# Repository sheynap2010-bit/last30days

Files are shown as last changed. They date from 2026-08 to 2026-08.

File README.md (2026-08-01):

# Strip case — print-in-place flip-top

A flat-oval capsule that holds 10 test strips (60 × 8 × 0.5 mm) and reads as a
lip balm stick. Prints upright, closed, in one piece, no supports.

```
src/geom.py             SDF kernel, marching tetrahedra, STL writer
src/model.py            the model — all geometry and every parameter
src/build.py            polygonise and export
src/check.py            verification; every number in the report comes from here
src/diag.py             locates what check.py counts
src/build123d_model.py  B-rep transcription for STEP export (NEVER RUN — see below)
src/blender_setup.py    builds the .blend inside Blender (NEVER RUN — see below)
out/strip_case.stl      both parts, closed, print-in-place — this is the print
out/strip_case_body.stl,
out/strip_case_cap.stl  the same two solids split out, world coordinates
out/strip_case.obj      both solids as named objects, for Blender
out/verification.txt    the full check output
out/render.png          shaded 3/4 view, closed and open at 105 deg
out/views.png           flat silhouettes: front, side, side open
out/strip_case_stl.zip  all three STLs, compressed
```

Regenerate: `cd src && python3 check.py 0.3` (no dependencies, stdlib only).
The argument is the marching grid in mm; it builds the meshes, writes `out/`,
and runs every check.

## What it is

| | |
|---|---|
| Envelope | **Ø18 × 94 mm** — a cylinder with hemispherical ends |
| Cavity | 10.8 × 7.0 stadium, 66.5 deep |
| Wall | 3.6 mm at the sides, 5.5 mm front and back, 2.2 mm cap |
| Hinge | **external** — Ø2.7 captive pins on a cap lug, Ø3.5 bores in two body ears |
| Latch | 8 × 1.8 × 11.65 mm cantilever, filleted root, 45° bead into a 45° groove |
| Keyring | Ø7.0 through the bottom dome |
| Mass | 19.9 g in PLA at 100% infill |

Coordinates: Z is the long axis with Z=0 on the bed, −Y is the back (hinge),
+Y is the front (latch).

The cross-section machinery is the same one that drew the earlier flat oval —
a stadium scaled to zero over each end along a circular profile. Setting the
width equal to the thickness collapses the stadium to a circle, so one code
path gives a true cylinder with domed ends and no special casing.

## Why the hinge is outside the skin — and why that seals the case

Opening rotates the cap about the pin, and **every point of the cap behind
the pin sinks as it rotates.** With the pin buried in the back wall the cap's
whole rear skin is behind it, so the body had to be hollowed out of its way —
and that hollow was a 2 mm slot from the cavity to open air, wide enough for
a 0.5 mm strip to escape. Four fixes were built and measured against that,
and all four failed:

| attempted fix | result |
|---|---|
| Full-size knuckle, cut back only at the ears | closes the split line, not the pocket — 2.45 mm |
| Cap tongue reaching into the pocket | seals it, but collides with the rim from 40° to 70° |
| Internal plug entering the bore | cannot print — its first layer is over 66 mm of air |
| Less opening angle | 100°: 2.02, 85°: 1.18, then **floors at 1.09 mm** down to 50° |

Moving the pin 0.15 mm **behind** the skin puts every point of the cap in
front of it. Everything rises on opening, nothing sweeps into the body, and
the split closes to its 0.3 mm print clearance the whole way round. The neck
survives as a complete 360° collar, which is what actually seals the bore.

That leaves only the cap's own lug, which hangs down behind the pin. It is
bounded by a cylinder on the pin axis, and radius is invariant under
rotation, so its swept envelope *is* that cylinder at every angle — the body
just carries a matching cylindrical recess. The recess is 3.0 mm deep into a
5.5 mm back wall: a dish in the outer surface, not a hole into the cavity.

**Consequences.** The model needs no swept-envelope subtraction, no dish and
no knuckle cut; every hinge clearance is now an explicit cylinder on the
axis. The swing test is clean across the *entire* 0–120° sweep rather than
stopping at 100°, and the cap's steep-overhang area dropped from 4.2 % to
0.9 % because all that relief geometry is gone. The cost is visual: the ears
stand 3.1 mm proud of the barrel and the cap's lug 2.7 mm, like a real
flip-top lip balm.

## Printing

Upright, closed, as modelled. Z = 0 is the bed. **Layer height 0.20 mm** —
the clearances are sized as whole multiples of it.

### The clearances are deliberately not all the same

| interface | gap | direction |
|---|---|---|
| split line, body top → cap bottom | **0.60 mm** | horizontal |
| lug → its recess in the body | **0.50 mm** | horizontal underneath |
| pin → bore | 0.40 mm radial | |
| neck → skirt, ear → lug | 0.30 mm | vertical |
| latch slot | 0.45 mm | vertical |

A **vertical** gap is safe at 0.3 mm because the nozzle never enters it. A
**horizontal** one is not: the layer above it is laid down over air, and at
0.3 mm with 0.20 mm layers that is 1.5 layers — the cap's first layer lands
almost on the body's top face and welds to it. 0.60 mm is three layers, so at
least two are completely empty. This is the single change most likely to
decide whether the cap comes free.

The latch slot runs the other way: it has to stay **under** the 0.5 mm strip
thickness, because it leads from the cap's interior, down past the tab and
out through the skin. At 0.6 mm a strip walks straight out of it. 0.45 mm
blocks the strip, and being vertical it still prints cleanly.

### Slicer settings that matter

- **0.20 mm layers.** Not 0.25 or 0.3 — the split stops being a whole number
  of layers and the gap starts closing.
- **Gap fill off** (PrusaSlicer/Orca: "Fill gaps" / minimum feature size).
  Otherwise the slicer may lay a thin extrusion into the 0.45 mm latch slot
  and weld the tab solid.
- 3 perimeters. The thinnest structural section is the 1.0 mm membrane
  between the cavity and the latch pocket.
- **No supports anywhere except under the bottom dome.**

### Supports: none

`strip_case.stl` ships with the bottom truncated 2.64 mm — the exact 45°
limit — giving **124 mm² of bed contact and no support anywhere in the
print**. A layer-by-layer scan at 0.20 mm finds only three places where
material starts without something under it:

| z | area | what it is |
|---|---|---|
| 76.80 | 57 mm² | the cap's first layer, bridging the 0.6 mm split |
| 70.0–70.2 | 6.7 mm² | the lug's underside, 0.5 mm over its recess |
| 71.4 | 4.5 mm² | the pin's underside, 0.4 mm over the bore |

All three are short bridges onto solid material directly below, which is
exactly what a print-in-place mechanism is. The cap's bottom outer edge is
chamfered 0.8 mm at 45°, which starts that first layer as a narrower ring and
grows it outward — it cut the bridged area from 101 mm² to 57 mm².

For the full hemisphere instead, set `BOT_FLAT = 0.0` in `model.py` and
rebuild. It then needs a brim and support under the lowest ~3 mm.

### The latch

| | |
|---|---|
| force to deflect the tab 0.45 mm | 10.9 N |
| **force at your thumb to open** | **~18 N (1.8 kgf)** |
| force holding it shut | the same — the bead's faces are symmetric |
| peak nominal strain | 0.89 % at z = 67.4, above the fillet |

The opening force is not the deflection force. The bead's 45° face is a cam,
so releasing it costs `F(μ + tan45°)/(1 − μ·tan45°)` — about 1.86× with PLA on
PLA — and the hinge lever trims it slightly. This is firmer than the 8–12 N
the brief asked for; it will not open in a pocket. To soften it, take `TAB_T`
from 1.8 to about 1.5 mm.

**The root is filleted, and that matters more than the numbers suggest.** Peak
bending strain sits just above the fillet, not at the root — strain goes as
x/t², so the thickest section is not the worst one. The fillet barely changes
that nominal 0.89 %. What it removes is the *stress concentration*: a square
internal corner on a flexing feature runs Kt ≈ 2.5, and a 1.2 mm fillet on a
1.8 mm section brings it to roughly 1.3. On a notch-sensitive material like
PLA that is the difference between a part that survives a few hundred
open/close cycles and one that cracks at the corner.

The slots get a smaller 0.35 mm fillet — anything approaching their 0.45 mm
width would close them up and weld the tab to the body.

### First open

The two parts are never fused in the model — intersection is 0.0000 mm³ — but
first-layer squish or a little stringing can tack them. Open it slowly the
first time; it should break free under light thumb pressure. If it resists,
run a thin blade round the split line rather than forcing it.

## Deviations from the brief, and why

**Cavity 10.8 × 7.0, not 10 × 6.5.** A 10 × 6.5 stadium does not actually
contain an 8 × 5 bundle: the bundle's corners sit 3.363 mm from the section's
arc centre against a 3.25 mm radius, so they foul by 0.11 mm. 10.8 × 7.0 is the
smallest stadium of that proportion that swallows the bundle, with 0.21 mm to
spare.

**Wall 2.7 mm around the cavity, not 2.0–2.5.** Forced by the other two
constraints: a 1.70 : 1 outer oval around a 10.8 × 7.0 cavity, with the pin
bore buried in the back wall, cannot have a thinner wall. The brief says the
strips and the wall win over the envelope, so the envelope moved instead —
21.1 × 12.4 rather than 24 × 14.

**The cavity's front wall tapers** from 3.5 to 2.75 mm off centre over the top
7.85 mm. That is what buys the neck enough material to carry a 2.0 mm skirt,
which is what gives the latch groove 1.45 mm of cap wall behind it. Slope is
15° from vertical. The opening still measures 6.25 mm front to back.

**Ears at x = ±6.0, pin at y = −2.56.** Not centred in the back wall. At the
ears' outer edge the oval's skin is only ±5.51 mm from the centre plane, so a
pin further back would break the bore out through the outside face — the exact
failure mode the brief called out. This position gives exactly 1.20 mm of
material all round the bore.

## OPEN ISSUE: the closed case is not sealed at the back

`check.py` section 4 measures this directly, and it currently reports that an
8 × 0.5 mm strip **can** escape. Do not treat this design as strip-tight yet.

Measured gap between the body's top and the cap's bottom, around the
perimeter of the closed case:

| bearing | gap |
|---|---|
| front and sides (0–75°, 285–345°) | **0.31 mm** — just the print clearance |
| 90° / 270° (sides) | 0.80 mm |
| 105° / 255° | 1.69 mm |
| 150° / 210° (back) | **2.02 mm** |

### Why it cannot be closed with the pin where it is

Opening rotates the cap about the pin. Every point of the cap *behind* the
pin sinks as it rotates, so the body has to be hollowed out of its way — and
that hollow is the opening. The pin sits inside the back wall, so the cap's
whole rear skin is behind it.

Four fixes were built and measured; all failed:

- **Full-size knuckle** (radius 5.02 instead of 4.54, cut back only in the
  two ear bands): closes the split line but not the pocket — 2.45 mm.
- **Cap tongue** reaching below the split into the pocket: seals it (the
  1.2 mm ball test passes), but the tongue swings forward and collides with
  the body's rim from 40° to 70°.
- **Internal plug** entering the bore: cannot print. Anything that enters the
  bore starts its first layer over 66 mm of open air.
- **Less opening angle**: 100° → 2.02 mm, 85° → 1.18 mm, and then it floors
  at **1.09 mm** all the way down to 50°. The knuckle sets that floor, not
  the tail. Still passes a 0.5 mm strip.

### The fix that does work

Move the pin *behind* the rear skin, at y ≈ −6.35. Then every point of the
cap is in front of the pin, everything rises on opening, nothing sweeps into
the body at all — the neck stays a full 360° collar, the rim stays intact,
and the split closes to 0.3 mm the whole way round.

The cost is visual: the hinge becomes an external boss. A Ø3.5 bore needs
1.2 mm of material round it, so the ears stand about 3 mm proud of the back,
with a matching strap on the cap. That is what a real flip-top lip balm looks
like, but it is not the flush silhouette this design was asked for. **It has
not been built** — it needs a decision first, because it trades the
appearance requirement against the containment requirement.

## Deviations from the brief, and why (continued)

## Deliverables that could not be produced here

Outbound network access is blocked by this environment's egress policy —
`pypi.org`, `archive.ubuntu.com` and `registry.npmjs.org` all return 403 through
the proxy. So:

- **No STEP.** build123d, CadQuery and OCP could not be installed.
  `src/build123d_model.py` is a faithful transcription that exports STEP, but
  **it has never been executed** and should be treated as unrun source. It
  imports its parameters from `model.py` so the two cannot drift.
- **No .blend.** Blender and `bpy` are not installed and could not be fetched,
  and a `.blend` is a binary dump of Blender's internal structures — not
  something worth hand-writing blind. Instead, one command on a machine that
  has Blender produces it:

  ```
  blender --background --python src/blender_setup.py     # writes out/strip_case.blend
  ```

  That script does more than import the mesh. It sets the scene to
  millimetres, and it moves the cap's origin onto the hinge pin axis
  (y = −2.56, z = 78.60) with a rotation limit of 0–105° on X — so the cap
  articulates about the real hinge instead of the world origin, over exactly
  the range the swing test cleared. It has also never been run; it is
  defensive about the operators Blender renamed in 3.3 and 4.2.

  If you would rather do it by hand, `out/strip_case.obj` carries the two
  solids as named objects (`body`, `cap`) and imports in one step — but the
  cap will pivot about the world origin until you move its origin yourself.

The STL is the verified deliverable. It comes from `model.py`, and `check.py`
runs against the same functions the STL was generated from.

## Verified numbers

From `out/verification.txt`, 0.30 mm marching grid:

| | |
|---|---|
| Topology | both solids watertight, 0 non-manifold edges, 1 component each |
| Closed-position intersection | **0.0000 mm³** (0 of 340k lattice cells inside both) |
| Swing 0–105° | **no hinge contact at any station** |
| Swing 110°+ | contact — this is the end stop, past the 100° requirement |
| Latch at 5° | 0.12 mm contact on the bead only: the detent releasing |
| Bottom | full R10.55 round, 0 mm² bed contact — needs a brim + tip support |
| Wall round the pin hole | 1.20 mm (need ≥ 1.2) |
| Bundle clearance | +0.21 mm at the corners |
| Cavity enclosed to | z = 74.6; strips reach z = 71.5 → 3.1 mm margin |
| Latch force | 10.1 N (target 8–12) |
| Latch peak strain | 0.91 % (PLA yields near 2–3 %) |
| Mass | 16.95 g at 100 % infill |
| Steep overhangs | body 2.16 %, cap 4.17 % — most of the body figure is the round bottom, by design |

The swing test rotates the cap about the pin axis in 5° steps and evaluates
the body's SDF at ~6000 cap-surface points per station. Contact at 5° is
confined to the latch bead and is reported separately: the cantilever is
meant to deflect there. Everything else is hinge interference and there is
none of it below 110°.

### The overhangs that remain

Counted from SDF gradients, not facet normals, at 46° (1° of slack on the
45° limit). Surfaces with material within 0.6 mm directly below are counted
separately — they bridge a gap rather than print over air, which is the
premise of a print-in-place mechanism.

What is left is genuinely unsupported, and it is worth knowing where:

- **The cap's bottom rim over the hinge relief at the back** (worst case,
  90°). The body's rear shoulder is scalloped away so the cap can rotate, so
  the cap's rim there overhangs 1–2 mm of air. Unavoidable on a hinge that
  opens past 100°; it bridges.
- **The ears' undersides** where the swept relief rounds them off, about
  1–2 mm across each.
- **The teardrop ridges** over the keyring and pin bores. The two 45° faces
  meet in a ridge carrying a 0.3 mm radius, so the very top of that radius is
  briefly horizontal. Not a real overhang.
- **The pin's first layer** floats 0.4 mm above the bore's floor — that is
  the mandated Ø2.7-in-Ø3.5 radial clearance, and it is how every
  print-in-place pin hinge behaves.

## Printing

Upright, closed, as modelled. Z = 0 is the bed.

- **Brim, plus support under the bottom ~3 mm.** The round bottom demands it.
- 0.3 mm clearance on every print-in-place gap; 0.4 mm radial on the pin
- 0.2 mm layers, 3 perimeters. The thinnest structural section is the 1.19 mm
  tip of the latch cantilever.
- No supports. Every hole with a horizontal axis — both pin bores and the
  keyring — is teardropped with a 45° gable roof rather than left round.
- The pin's underside is a 45° V rather than a cylinder, so it self-supports.

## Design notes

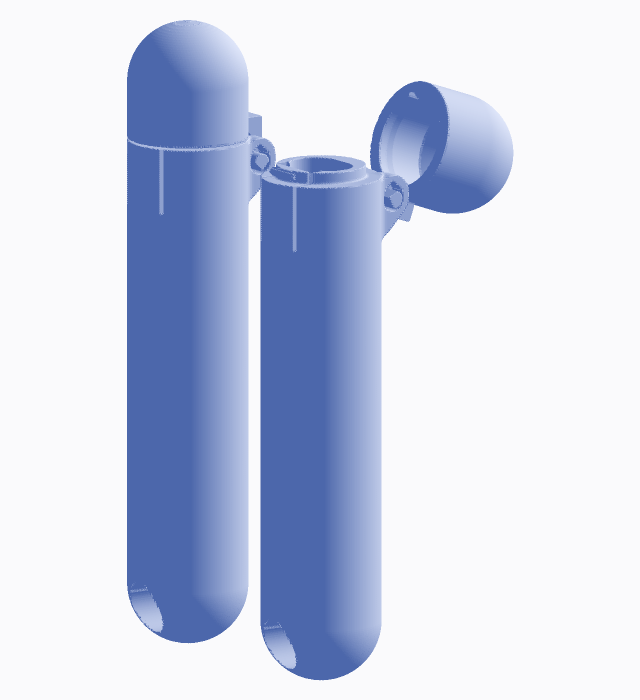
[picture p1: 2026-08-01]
out/render.png

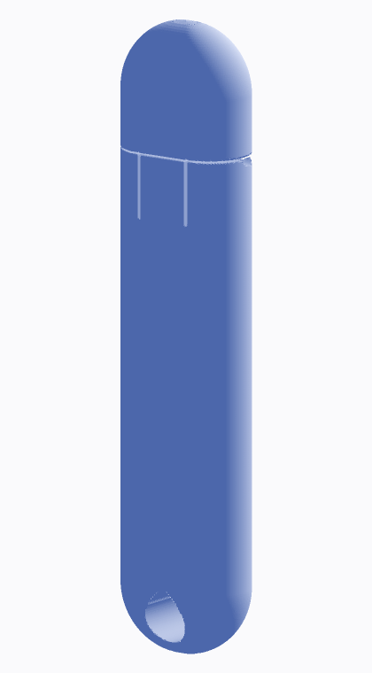
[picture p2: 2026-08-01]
out/shaded.png

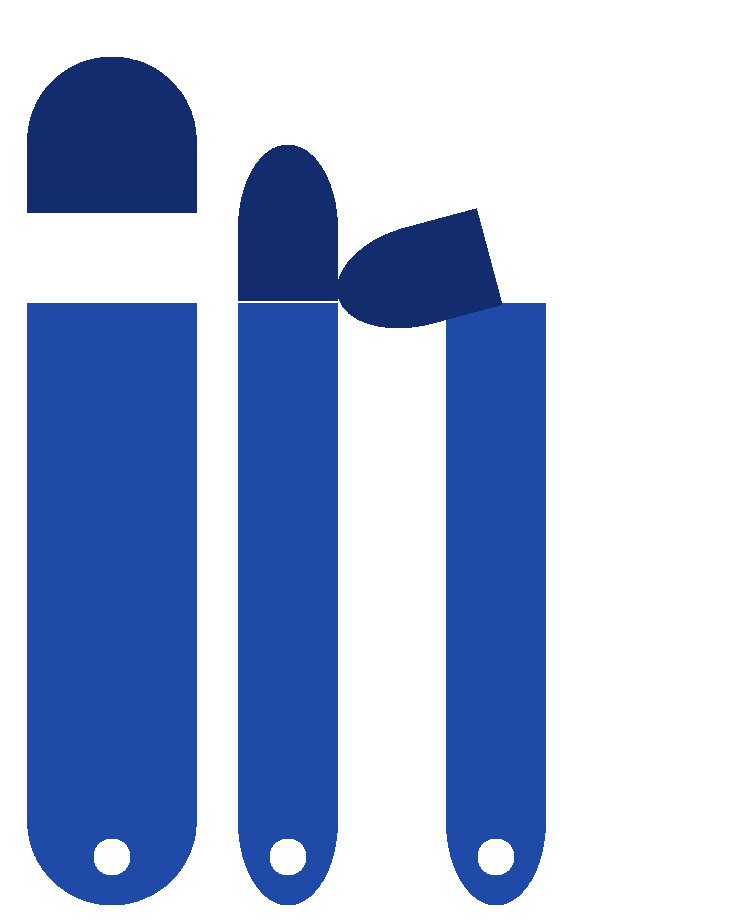
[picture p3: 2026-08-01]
out/views.png

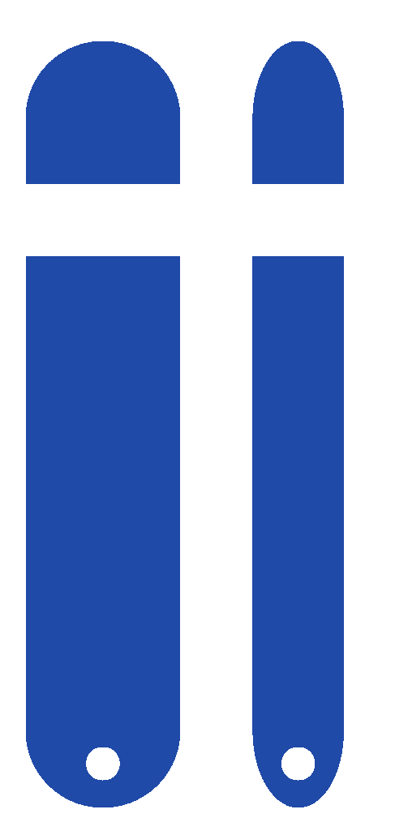
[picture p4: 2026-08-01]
out/silhouette.png

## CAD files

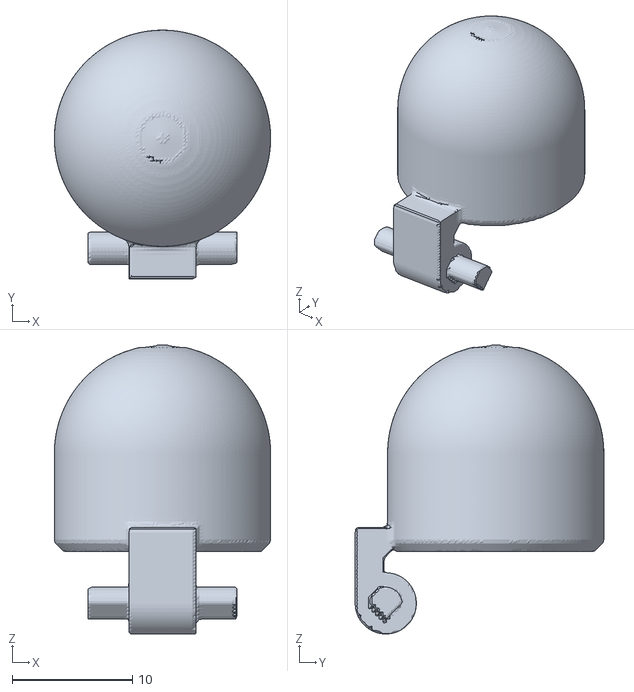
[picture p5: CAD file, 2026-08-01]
out/strip_case_cap.stl
18.0 x 20.7 x 24.1

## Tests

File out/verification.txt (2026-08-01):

grid step 0.30 mm
  body  sample  17.7s  march   9.6s  smooth  23.4s  358264 verts (74036 relaxed)  716536 tris
  cap   sample   2.4s  march   1.8s  smooth   2.5s   87896 verts (17338 relaxed)  175788 tris
  volume body  14131.2 mm^3  cap   2409.4 mm^3  total  16540.6
  mass at 100% infill: 20.51 g
  wrote 892324 triangles to out/strip_case.stl

1. topology
-----------
  body  watertight True   single solid True   (non-manifold edges 0, components 1)
  cap   watertight True   single solid True   (non-manifold edges 0, components 1)

2. closed position -- volume intersection
-----------------------------------------
  lattice 89 x 89 x 91 at 0.25 mm over the overlap region
  cells inside BOTH solids: 0  ->  intersection volume 0.0000 mm^3

3. swing test, 0 to 120 deg about the pin axis
----------------------------------------------
  6000 cap-surface sample points per station

   angle   hinge hits  deepest    latch hits  note
      0          0      0.0000          0    
      5          0      0.0000          0    
     10          0      0.0000          0    
     15          0      0.0000          0    
     20          0      0.0000          0    
     25          0      0.0000          0    
     30          0      0.0000          0    
     35          0      0.0000          0    
     40          0      0.0000          0    
     45          0      0.0000          0    
     50          0      0.0000          0    
     55          0      0.0000          0    
     60          0      0.0000          0    
     65          0      0.0000          0    
     70          0      0.0000          0    
     75          0      0.0000          0    
     80          0      0.0000          0    
     85          0      0.0000          0    
     90          0      0.0000          0    
     95          0      0.0000          0    
    100          0      0.0000          0    
    105          0      0.0000          0    
    110          0      0.0000          0    
    115          0      0.0000          0    
    120          0      0.0000          0    

4. containment -- can a strip escape when closed?
-------------------------------------------------
  lattice 89 x 89 x 73 at 0.25 mm
    ball  Ø0.5 mm : contained
    ball  Ø0.8 mm : contained
    ball  Ø1.2 mm : contained
    strip 8 x 0.5 mm : CONTAINED
        no path out can host an 8 mm wide strip in any
        axis-aligned orientation -- the strips stay in

5. measurements
---------------
  bottom truncation 2.64 mm  ->  bed contact 124.0 mm^2
  material between the pin hole and the ear surface: 1.20 mm
        thinnest at 89 deg round the axis, ear at x = -4.5   (need >= 1.2)
  cavity  10.81 wide x 7.00 thick x 66.50 deep
  section at mid strip: 7.01 mm back to front (-3.50 to +3.50)
  fully enclosed up to z = 78.0; strips reach z = 71.5  -> 6.5 mm of margin
  bundle  8.00 wide x 5.00 thick x 60.00 long (10 x 0.5 mm strips)
  clearance at the bundle corners: +0.21 mm, best seating y = +0.00
        (measured above the 0.6 mm fillet at the cavity floor)
  retrieval margin over the 60 mm strip: 6.50 mm
  tab: 8.0 wide x 1.80-4.01 thick x 11.65 long
  bead 0.75 proud, 0.45 engaged past the skirt (0.30 is clearance)
  force to deflect it clear of the groove: 10.9 N   (target 8-12)
  peak surface strain at the root: 0.48 %   (PLA yields near 2-3 %)
  body  surface samples steeper than 45 deg: 363 of 39283 (0.92 %)
        (plus 45 with material within 0.6 mm directly below -- those bridge a gap, they do not print over air)
        worst 89 deg at (0.00, -3.21, 10.72)
  cap   surface samples steeper than 45 deg: 1481 of 40000 (3.70 %)
        (plus 264 with material within 0.6 mm directly below -- those bridge a gap, they do not print over air)
        worst 90 deg at (-1.15, -7.99, 76.83)

6. mass
-------
  body 14131.2 mm^3, cap 2409.4 mm^3, total 16540.6 mm^3
  PLA at 1.24 g/cm^3, 100% infill: 20.51 g

summary
-------
  topology ok        : True
  closed-position hits: 0
  swing stations with interference: 0

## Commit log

2026-08-01 Strip case: print-in-place flip-top, flat-oval capsule
    Holds 10 strips of 60 x 8 x 0.5 mm in a 10.8 x 7.0 stadium cavity,
    68.65 mm deep. Outer envelope 21.1 x 12.4 x 88, stadium section at
    1.70:1. Prints upright and closed with no supports.
    Modelled as composed signed distance functions rather than mesh
    booleans, so fillets are genuine constant-radius blends and collision
    tests are exact function evaluations rather than mesh queries.
    The rear hinge relief is a swept envelope: the body subtracts the cap's
    closest approach over the whole 0-105 degree opening range, which is
    correct by construction. Three hand-derived relief radii failed first.
    Verified at a 0.30 mm marching grid:
    - both s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
    [strip_case_cap.stl]
2026-08-01 README: correct enclosure figures, document the rear split-line gap
    The final 0.30 mm run measures full enclosure to z = 74.3, not 74.1, so
    the strips clear it by 5.3 mm rather than 5.1.
    Also records the one place the brief's flush-surface requirement is not
    met: the split line is flush at the front and sides but carries a 1.4 mm
    gap across the back, because the knuckle had to be cut back inside the
    ear relief to stop it sweeping into the ears' roots.
    Claude-Session: https://claude.ai/code/session_01H2Lk16H5eewQLcjQ4GMb8C
2026-08-01 Add Blender setup script for the .blend deliverable
    Blender still cannot be installed here, so this cannot be run in-session
    and is unverified. It reduces the .blend to one command on a machine that
    has Blender:
    blender --background --python src/blender_setup.py
    Beyond importing the mesh it sets the scene to millimetres and moves the
    cap's origin onto the hinge pin axis with a 0-105 degree rotation limit
    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
2026-08-01 Drop degenerate triangles from the exported STLs
    Marching tetrahedra emits zero-area triangles wherever an interpolated
    vertex lands on a lattice point. They are kept in the in-memory mesh
    because they carry connectivity the watertightness check needs, but STL
    is a triangle soup with no connectivity, so they are dead weight there.
    Removing them cuts the combined export from 798584 to 721320 triangles
    with no change to the surface. Geometry verified unchanged: bounding box
    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
    [strip_case_cap.stl]
2026-08-01 Reshape both ends: true U instead of a swept stadium
    The bottom read as a vape tube because the ends were rounded by sweeping
    the stadium cross section, which leaves a bottom that is flat across the
    middle with rounded corners. Both ends now scale the whole cross section
    to zero along a circular profile of radius HALF_W, so the front view of
    each end is an exact semicircle spanning the full width -- a U. This is a
    different surface, not a smaller radius.
    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
    [strip_case_cap.stl]
2026-08-01 Ø7 keyring hole, and smooth the mesh so it stops looking faceted
    Keyring goes Ø4.5 -> Ø7.0, closer to the reference proportion. It needs
    2.3 mm of material below it and 11.5 mm of clearance to the cavity floor,
    so the floor rises 11.0 -> 11.5 and the whole upper structure shifts up
    1 mm; the case grows 95 -> 96 mm and cavity depth is 66.5, keeping 6.5 mm
    of strip protruding for retrieval.
    The faceted look was not the grid pitch. Marching tetrahedra places each
    vertex where a lattice edge crosses the surface, which leaves slivers and
    an uneven distribution, and that is what shades badly. smooth_project()
    relaxes each vertex toward its neighbours then Newton-steps it back onto
    the exact is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
    [strip_case_cap.stl]
2026-08-01 Fix latch groove cutting a slot clean through the cap
    The groove region was (y - R_NECK) + |z - BEAD_Z| <= BEAD_R + GROOVE_GAP
    with no lower bound on y. Any sufficiently negative y satisfies it, so the
    groove was not a groove: it was a 6.4 mm wide channel cut straight through
    the cap from front to back at the bead's height, opening the cavity to the
    outside exactly where the strips are. Bounding it 0.6 mm inboard of the
    bead's root fixes it, and still leaves the bead clear of its own groove.
    Adds a containment check that measures the leak instead of arguing about
    it: it floods the void between the two closed solids from a seed inside the
    cavity and reports what size object can reach open ai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
    [strip_case_cap.stl]
2026-08-01 Cylindrical body, domed ends, external hinge -- the case now seals
    Ø18 cylinder with hemispherical ends, replacing the 21.1 x 12.4 flat oval.
    The section machinery is unchanged: setting width equal to thickness
    collapses the stadium to a circle, so one code path gives the cylinder.
    The hinge pin moves from inside the back wall to 0.15 mm behind the skin.
    That is what closes the case. Every point of the cap is now in front of
    the pin, so everything rises on opening and nothing sweeps into the body;
    the neck survives as a complete 360 degree collar and the split line
    closes to its 0.3 mm print clearance all the way round. Containment goes
    from "an 8 x 0.5 strip escapes" to "even a Ø0.5 ball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
    [strip_case_cap.stl]
2026-08-01 Tune clearances for print success, and add a flat-bottom variant
    The split line was a 0.30 mm HORIZONTAL gap, which is 1.5 layers at 0.20
    and the most likely place for the cap to weld itself to the body: the
    cap's first layer gets laid almost directly onto the body's top face. It
    is now 0.60 mm, three whole layers, so at least two are empty. The lug's
    recess gets the same treatment at 0.50 mm, since the lug's underside is
    also a horizontal interface. Vertical gaps stay at 0.30 -- the nozzle
    never enters those.
    Widening the latch slot to 0.6 for printability broke containment: the
    slot runs from the cap's interior, down past the tab and out through the
    skin, so at 0.6 mm a 0.5 mm strip walks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
    [strip_case_cap.stl]
2026-08-01 README: document the print clearances and the two bottom options
    Records which clearance runs which way and why -- horizontal gaps get
    0.60/0.50 mm because the layer above them is laid over air, vertical ones
    stay at 0.30 because the nozzle never enters them, and the latch slot is
    held at 0.45 because it must stay under the strip thickness.
    Also the two slicer settings that decide whether this works: 0.20 mm
    layers so the split stays a whole number of layers, and gap-fill off so
    the slicer cannot bridge the 0.45 mm slot and weld the latch tab.
    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
2026-08-01 Default to the support-free bottom, chamfer the cap's leading edge
    BOT_FLAT defaults to 2.6396 -- the exact 45 degree limit -- giving 124 mm^2
    of bed contact and no support anywhere in the print. The full hemisphere
    is still one line away for anyone who wants it.
    Adds a layer-by-layer scan for material that starts with nothing under it,
    which is the thing that actually predicts a failed print. Probing straight
    down gives false positives on every sloped surface, so it probes a
    neighbourhood one extrusion width across: a bead is anchored if material
    lies under any part of it. With the flat bottom it finds only three
    places, all short bridges onto solid material directly below -- the split
    lin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
    [strip_case_cap.stl]
2026-08-01 Fillet the latch tab's root, and measure peak strain where it actually is
    The pocket and slots arrived at the tab's root as square internal corners:
    a notch on the exact face that sees peak tension, on a feature that flexes
    every time the case is opened. PLA is notch sensitive, so that corner is
    where a fatigue crack starts. The pocket now blends into the root with a
    1.2 mm fillet; the slots get 0.35 mm, since a fillet approaching their
    0.45 mm width would close them and weld the tab to the body.
    The check was reporting strain at the root, which the fillet makes the
    THICKEST section -- so it appeared to halve, 0.92% -> 0.48%, for entirely
    the wrong reason. Strain goes as x/t^2, so the worst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
